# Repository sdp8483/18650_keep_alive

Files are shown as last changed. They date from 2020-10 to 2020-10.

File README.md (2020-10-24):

# 18650 Battery Shield Keep Alive Circuit

The following circuit was designed to keep the 5V rail of a 18650 Battery Shield active even with no load attached. A comparator will "press" the tactile switch when the 5V rail goes below the 3V3 rail.

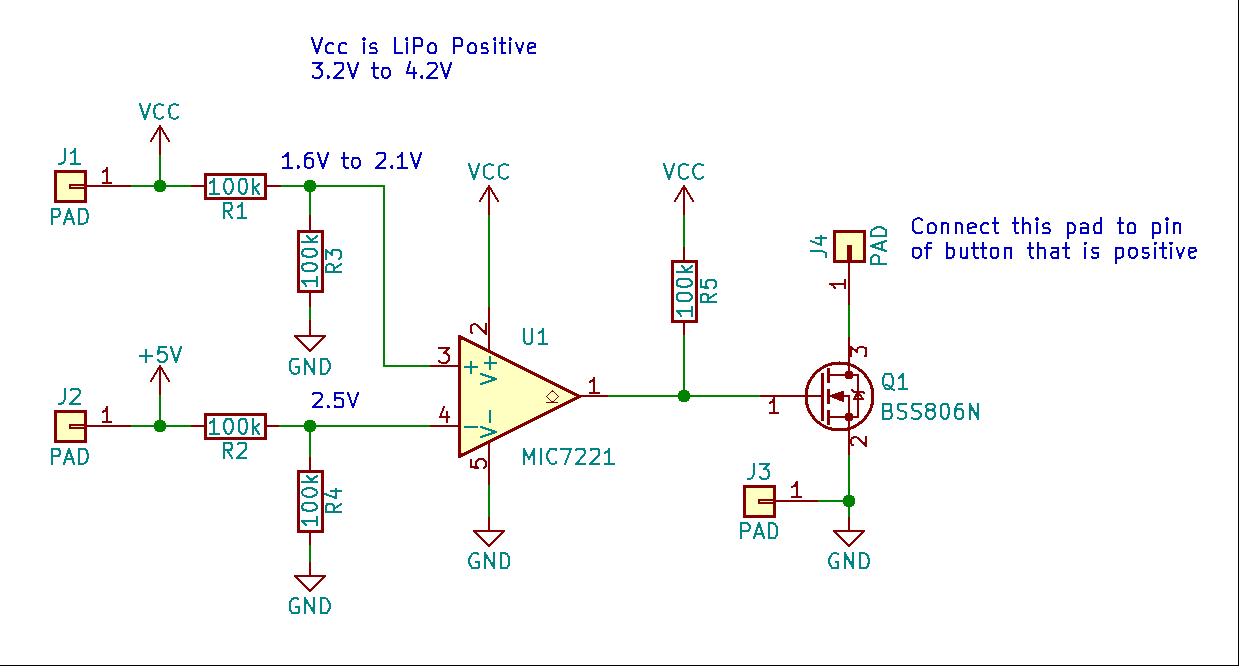
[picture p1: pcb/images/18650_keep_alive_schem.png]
Schematic


The circuit is built on a small one sided PCB that is attached to the battery shield using hot glue. Electrical connections are made using multi-strand wire.

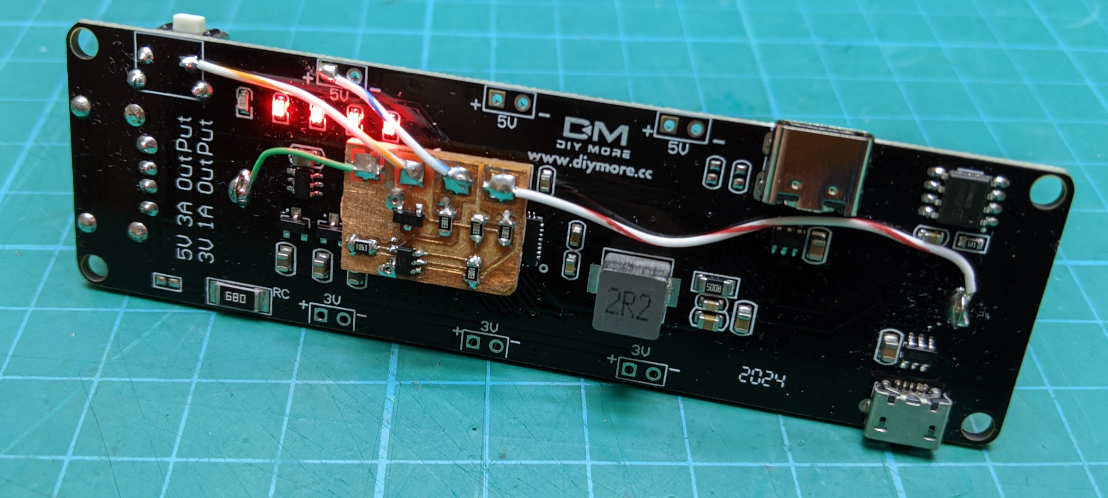
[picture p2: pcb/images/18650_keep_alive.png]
Keep Alive Installed


Below is a photo of an unmodified 18650 Battery Shield. They may use keywords such as ESP32 or Raspberry Pi battery shield.

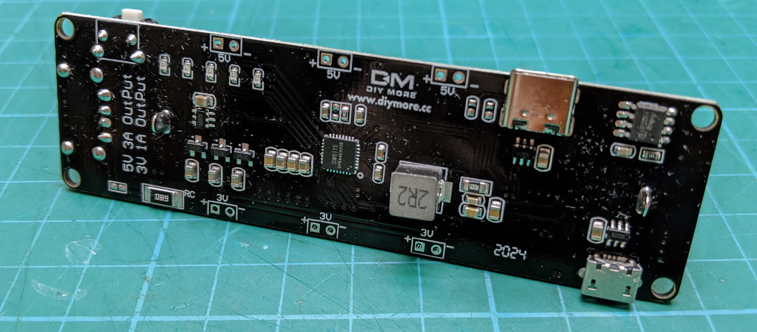
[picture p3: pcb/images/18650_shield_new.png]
18650 Battery Shield


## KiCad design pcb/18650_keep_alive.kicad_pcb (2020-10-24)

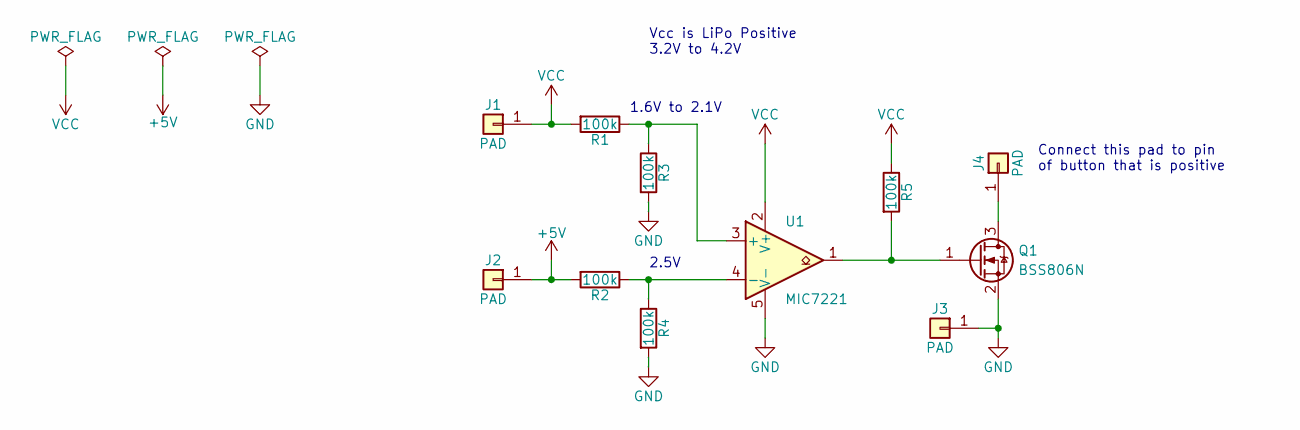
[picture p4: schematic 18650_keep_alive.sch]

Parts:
J1, J2, J3, J4: PAD; TestPoint_Pad_2.5x2.5mm
Q1: BSS806N; SOT-23
R1, R2, R3, R4, R5: 100k; R_0805_2012Metric
U1: MIC7221; SOT-23-5

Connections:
+5V: J2.1, R2.2
GND: J3.1, Q1.2 (S), R3.2, R4.2, U1.5 (V-)
unnamed: J4.1, Q1.3 (D)
unnamed: Q1.1 (G), R5.2, U1.1
unnamed: R1.1, R3.1, U1.3 (+)
unnamed: R2.1, R4.1, U1.4 (-)
VCC: J1.1, R1.2, R5.1, U1.2 (V+)

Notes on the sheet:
Vcc is LiPo Positive 3.2V to 4.2V
1.6V to 2.1V
2.5V
Connect this pad to pin of button that is positive

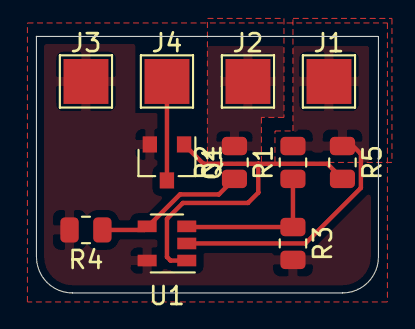
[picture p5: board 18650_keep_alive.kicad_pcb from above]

Board: 2 copper layers, 19.0 x 14.2 mm, 11 parts (0 on the bottom side), 7 nets.

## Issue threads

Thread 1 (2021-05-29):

Disconnecting when plug/unplug charger.

Travis90x, 2021-05-29:
How we can solve this problem?
<<I found this problem with almost all the commercial power banks BMSs (battery shield, charge and discharge protection for lithium 18650 3.7V batteries). Some of them behave this way only on connect, others only on disconnect, others on both situations.
When I connect or disconnect the charge cable, the output ports (PCB or USB, it doesn't matter), disconnect for 500 ms.
This test was made with a DiyMore V8 board, but it happens on all BMS boards i've tried so far (V9 also). They use IP3005A charge protection and SW6115 controller.
Therefore, this boards can't be used as UPS for ESP32, ESP8266, Arduino, Raspberry boards.>>
https://www.youtube.com/watch?v=1RxNaATtVqs

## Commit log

2020-10-23 init commit
    [18650_keep_alive.kicad_pcb, 18650_keep_alive.sch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]
2020-10-24 round corners, set zero upper right
    [18650_keep_alive.kicad_pcb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]
2020-10-24 update isolation cut to new orgin
2020-10-24 move gcode to inside gerber dir
    [18650_keep_alive-job.gbrjob]
